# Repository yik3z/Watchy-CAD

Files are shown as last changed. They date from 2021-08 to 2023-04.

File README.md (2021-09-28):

# Watchy-CAD
Cases and hardware mods for Watchy

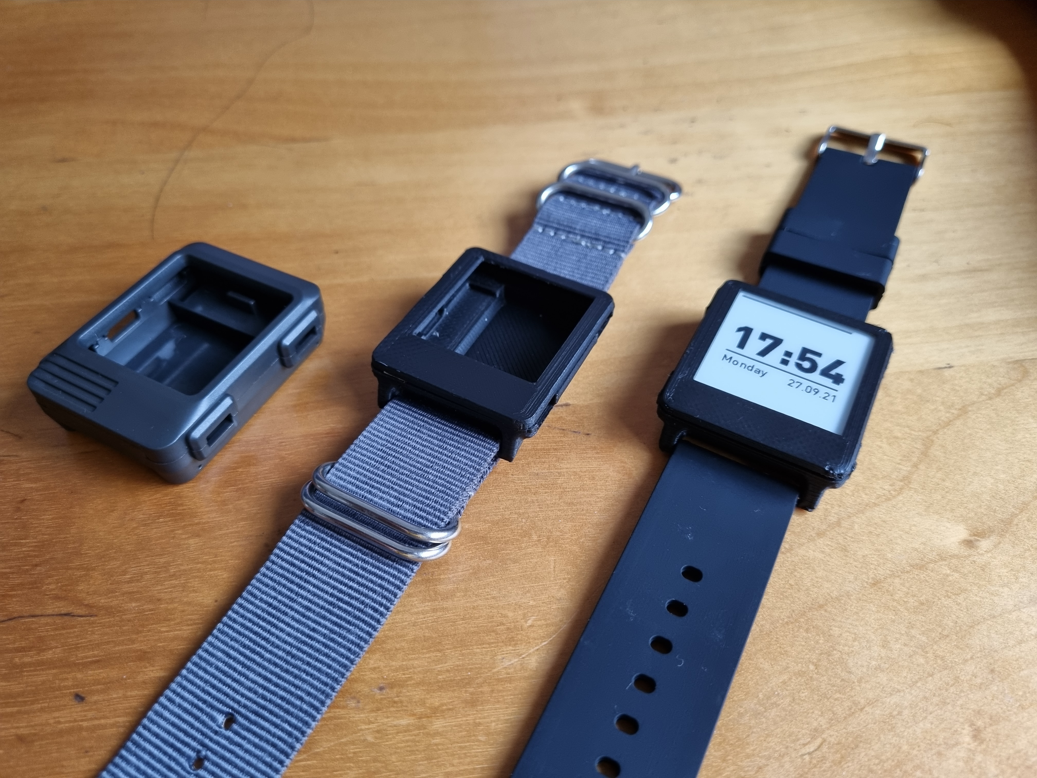
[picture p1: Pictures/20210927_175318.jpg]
Cases


# Cases
Cases are located under `CAD>Cases`. Each case design has the STLs under an `STLs` subfolder and STEP (AP214) files under the `STEP` folder.

### *Slim* cases to make Watchy less chonky

1. **Slim**: This is the original case from [SQFMI's watchy-cases](https://github.com/sqfmi/watchy-cases). Had some errors slicing the file, hence rebuilt it as Slim V2 

2. **Slim V2**: Insipred by the `Slim` case, designed for use with 24mm NATO straps.

3. **Slim V3**: **Designed for a Watchy with the watch strap loops cut off from the PCB.** Similar to Slim V2, designed for 24mm NATO straps.

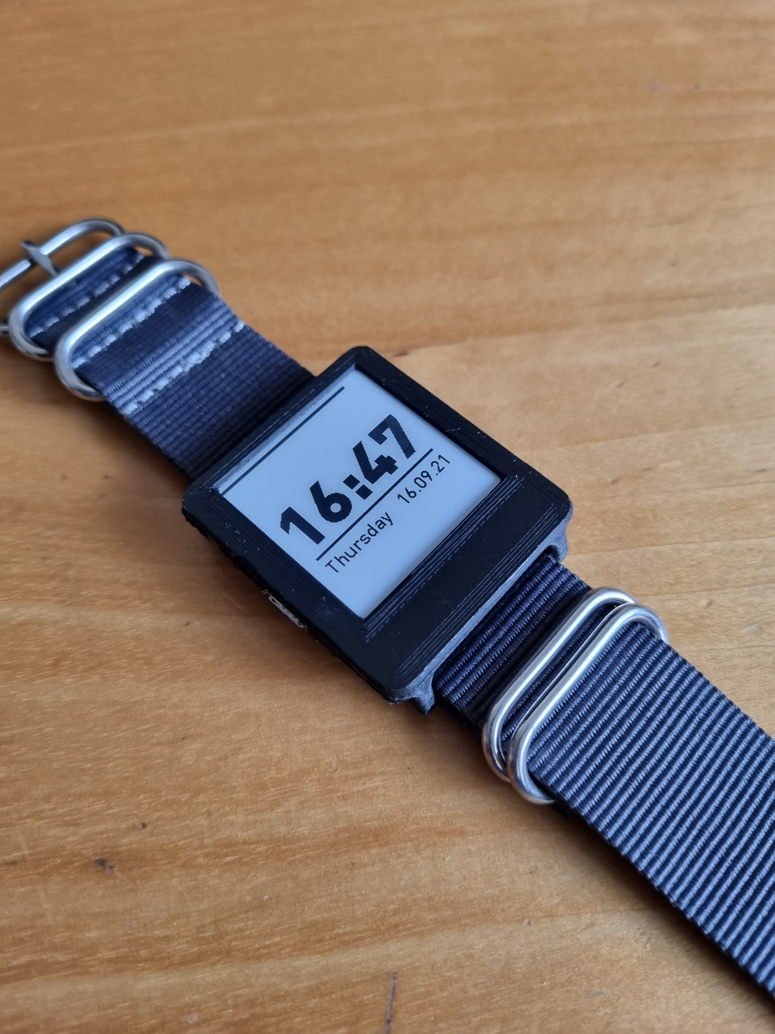
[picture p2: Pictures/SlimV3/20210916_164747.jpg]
SlimV4


I tried my hand at some discreet buttons on this, but they didn't work that well. **So, there aren't any buttons on this version.** I suggest you use the top case of `Slim V4` which has integrated buttons.

4. **Slim V4**: Similar to V3 , but tabs are changed to fit the spring pin -style straps of the Watchy starter kit (24mm). This lowers the height of Watchy significantly. 

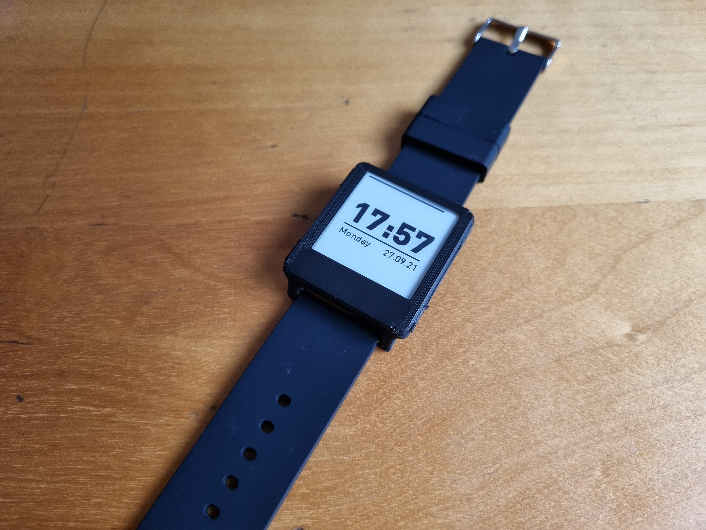
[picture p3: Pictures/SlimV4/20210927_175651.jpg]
SlimV4


In v4, I made the display window a little larger, for use with the [border colour changing 'hack' on the Watchy Discord](https://discord.com/channels/804832182006579270/808787590060048465/887013190616117288) so that the screen looks a bit bigger/bezel looks a bit smaller. If you don't want to implement the colour changing border, make the display window a little smaller (26.8mm instead of 28.4mm) otherwise there will be a white border around your display.

## Some Warnings/Notes
**Slim V3 and Slim V4 don't have any fastening mechanisms in place; they are currently held together by friction, and a bit of double-sided tape.** I find that it works well (it's pretty difficult to take the PCB out of the case, but use at your own risk). I find that the double sided tape loses it's adhesion after sticking and removing it a few times, so it's a good idea to put a fresh piece of tape every few times you take it apart.

**The Slim V3 and V4 may or may not close fully if you have the stock battery cable. I shortened mine so there is less wire taking up space in the case. [See below](##-shorten-battery-wires) for details.** It allows the case to be 1mm thinner.  If you don't want to cut the battery wires, you can just make the case 1mm deeper :P

These cases were designed on Autodesk Inventor. The raw files are included in case you'd like to modify them. 

Slim V3 and V4 parts are interchangeable (top and bottom).

Also, tolerances may vary based on 3d printer.

## Upcoming Stuff
- Clipping mechanism to make the case more secure

# Hardware Mods

## Cutting off PCB loops

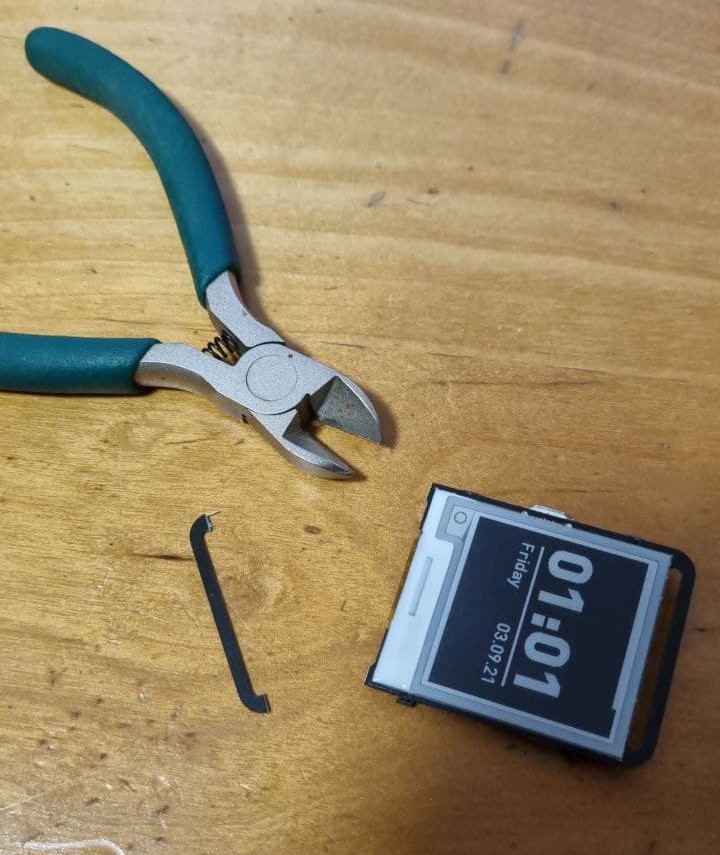
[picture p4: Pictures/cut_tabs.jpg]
cut tabs


(Guide may be coming soon)

## Shorten Battery Wires
1. Cut the wires.
2. Cut off excess.
3. Slip on some heatshrink.
4. Solder the wires back.
5. Heatshrink.

It's a good idea to do each wire separately so there's no chance that the + and - wires will ever touch.

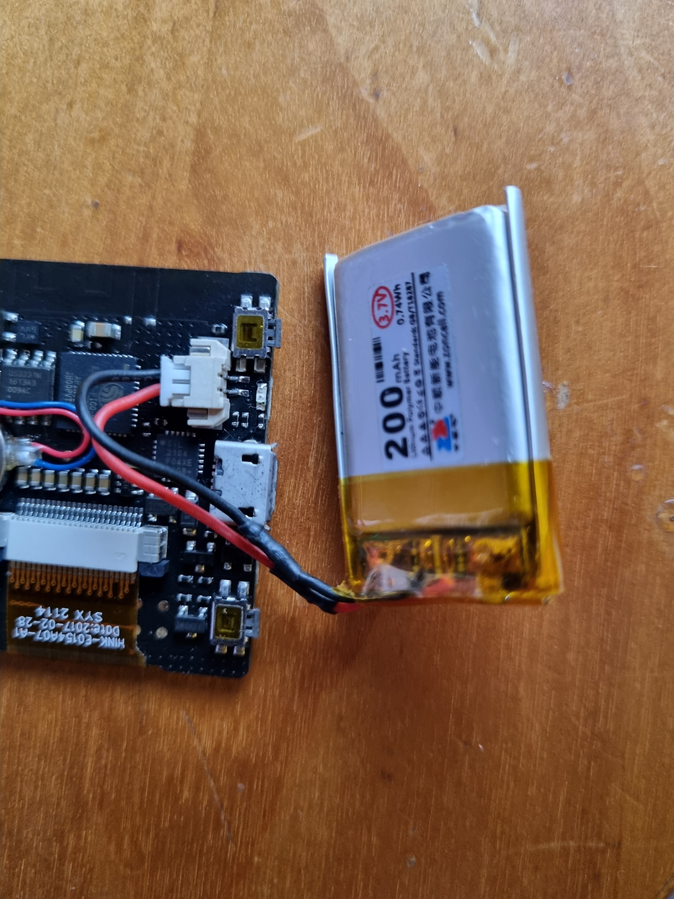
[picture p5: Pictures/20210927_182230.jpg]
shortened wire


## Touchscreen
(coming soon too hopefully hehe)
The plan: integrate [this touchscreen](https://www.good-display.com/product/258.html) with Watchy. Is currently shipping. Will update progress soon.

## Battery Charging indicator
Idea is to connect the charging controller to the ESP32's GPIO and set an interrupt so it knows when it's charging.
*Fundamentally this is problematic - Watchy may never be able to wake from sleep upon connecting a charger.*

Explanation: the charging IC pulls pin 1 low when charger is connected. ESP32 can only have one GPIO pin configured (at a time) to wake it from sleep when the pin goes low (using `ext0`). Currently that is connected to the RTC (removing that means Watchy stops being a watch). An alternative is to use an inverter, but...that's a lot of work. So this mod may not happen. At least not the wake from deep sleep part

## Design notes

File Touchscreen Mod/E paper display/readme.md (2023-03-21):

# 154M09 Display

The display might be a bit faulty because it is always very light no matter what VCOM or settings are used. (Even with Good Display's sample code).
So I have stopped development on this, and will be using the familiar 154D67 display for the touchscreen instead.

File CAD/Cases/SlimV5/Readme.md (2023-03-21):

# Version 5 of Slim Case

V5 has a bigger battery: 402535 instead of 402030
This version is for a watchy with the strap loops removed. For a smaller footprint

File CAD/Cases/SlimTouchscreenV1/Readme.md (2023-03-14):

# Version 1 of Slim Case for Touchscreen watchy

In progress

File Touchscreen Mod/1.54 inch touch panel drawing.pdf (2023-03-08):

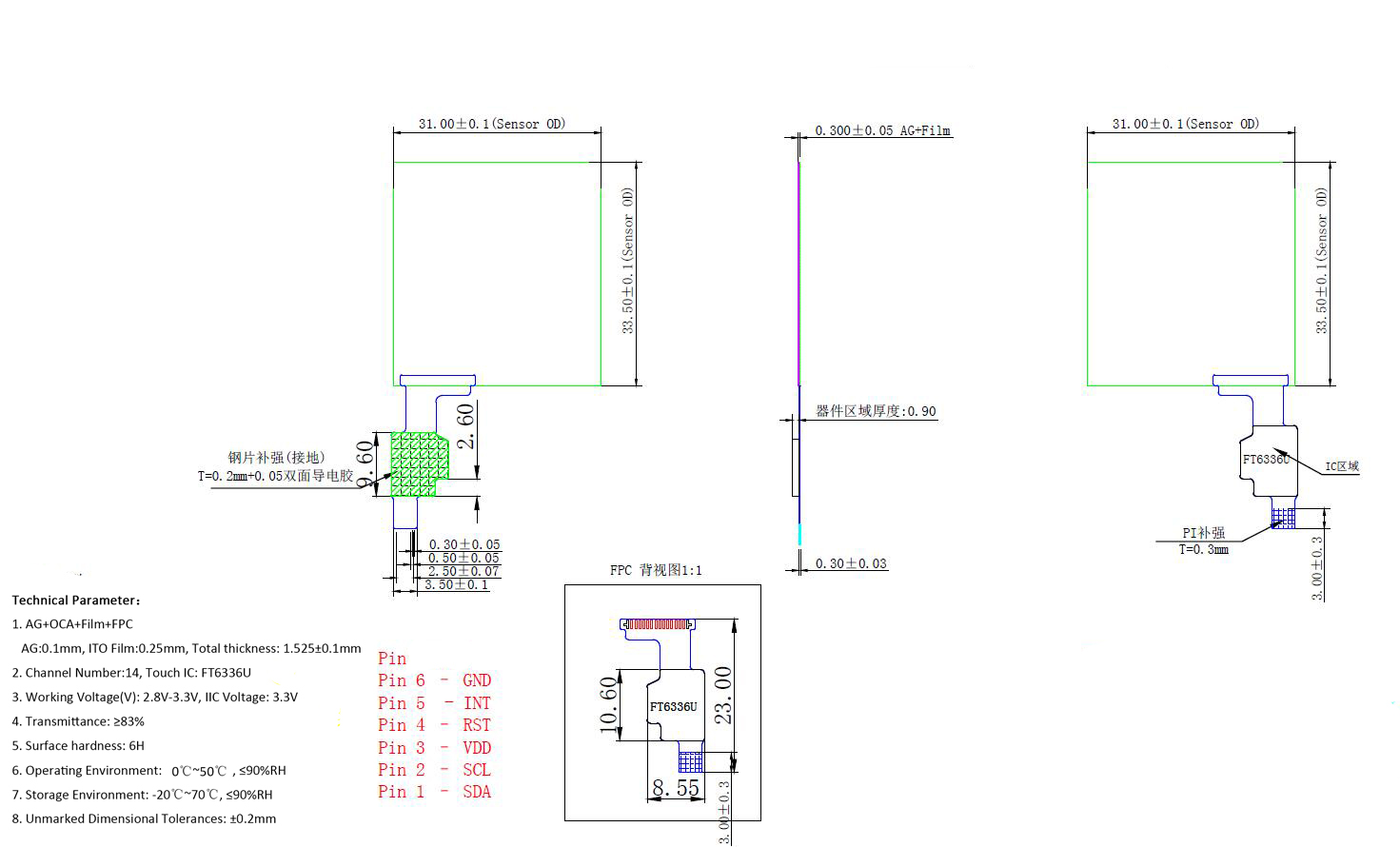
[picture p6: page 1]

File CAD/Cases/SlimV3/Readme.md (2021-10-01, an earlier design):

# Version 3 of Slim Case

This version is for a watchy with the PCB strap loops removed. For a smaller footprint

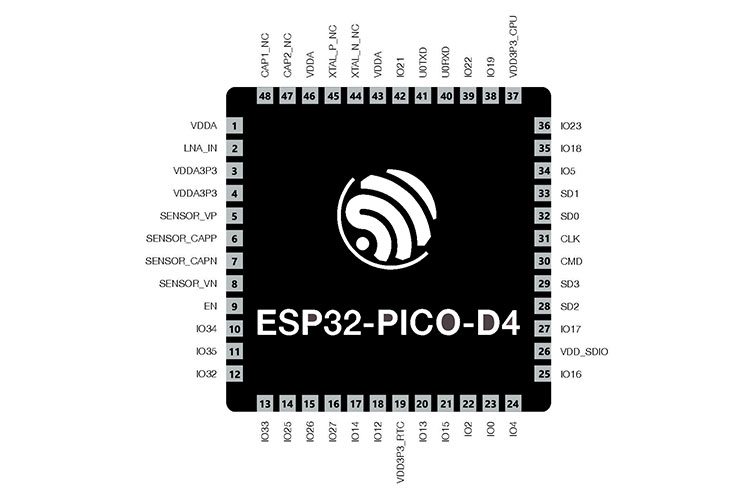
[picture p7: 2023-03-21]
Datasheets/esp32-pico-d4-pinout.jpg

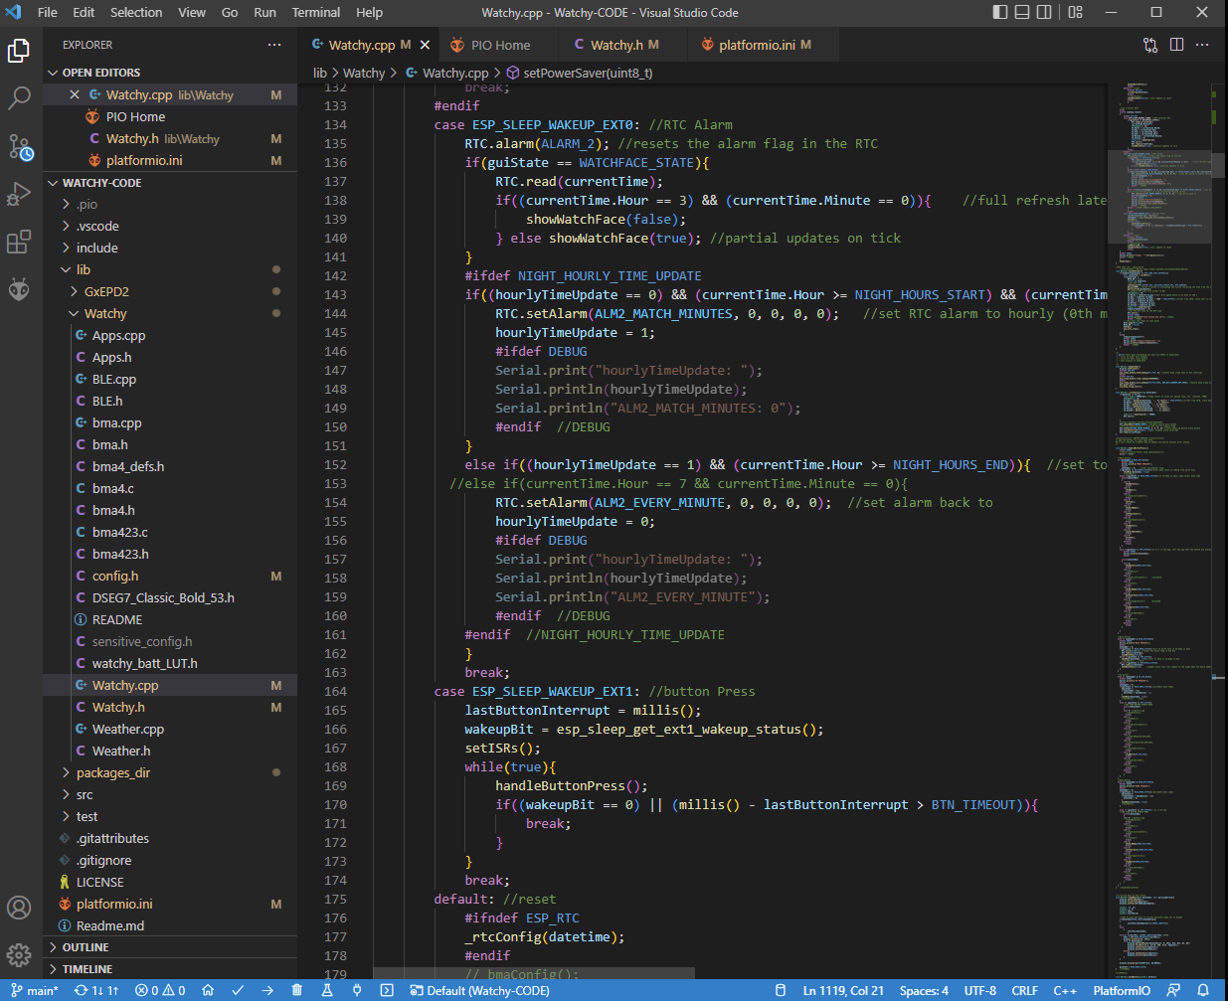
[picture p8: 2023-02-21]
Pictures/Programming.png

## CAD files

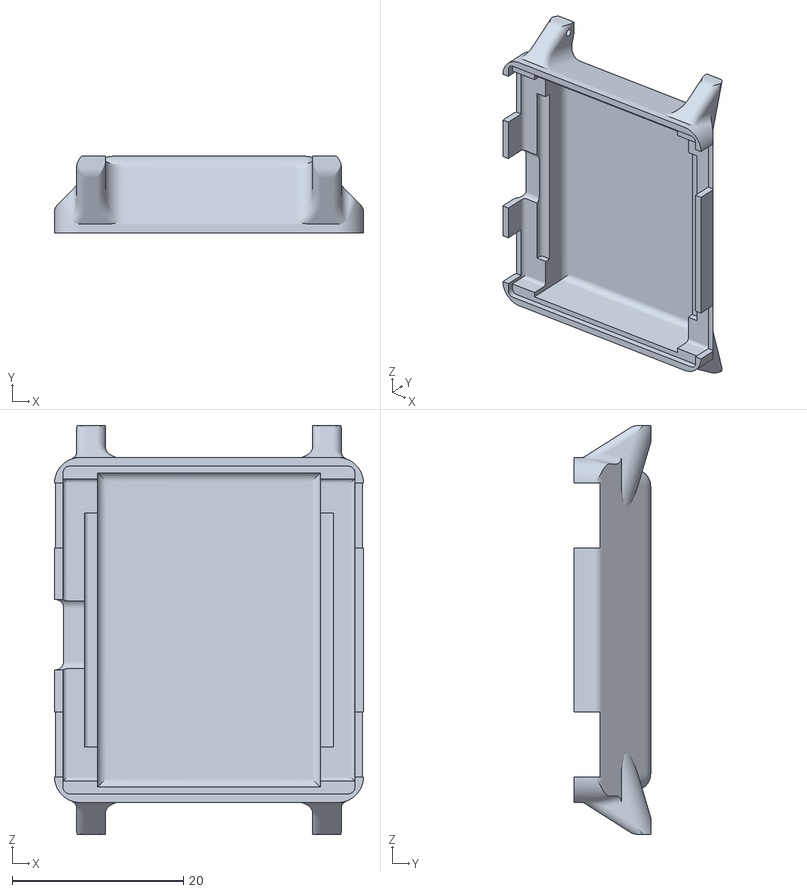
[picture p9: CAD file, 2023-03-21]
CAD/Cases/SlimV5/STLs/Bottom170323.stl
36.1 x 8.94 x 47.8

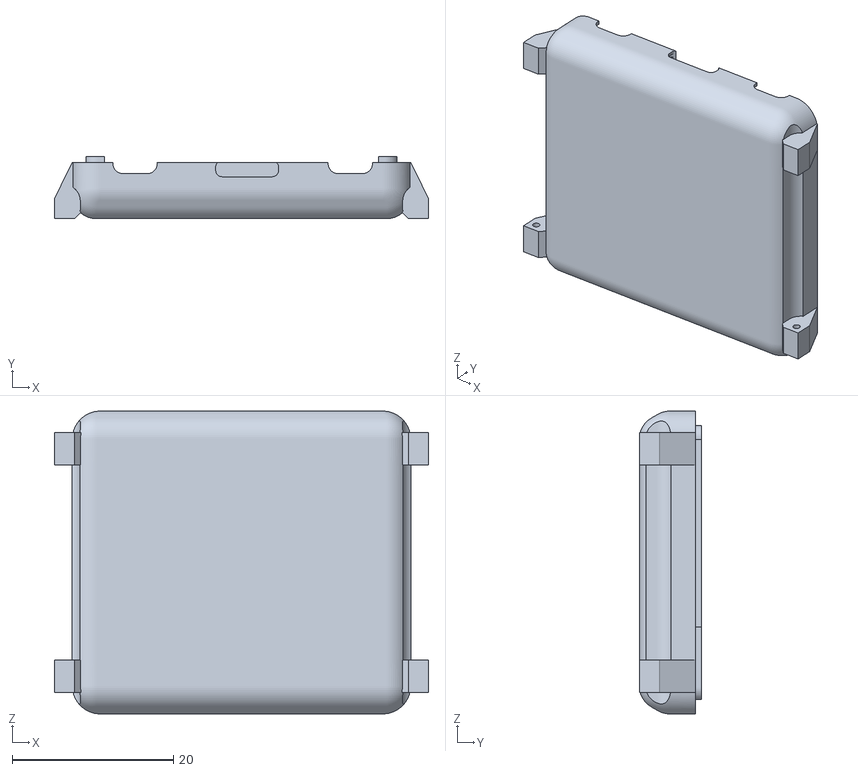
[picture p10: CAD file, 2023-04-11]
CAD/Cases/SlimTouchscreenV1/STLs/Bottom060423.stl
46.4 x 7.74 x 37.6

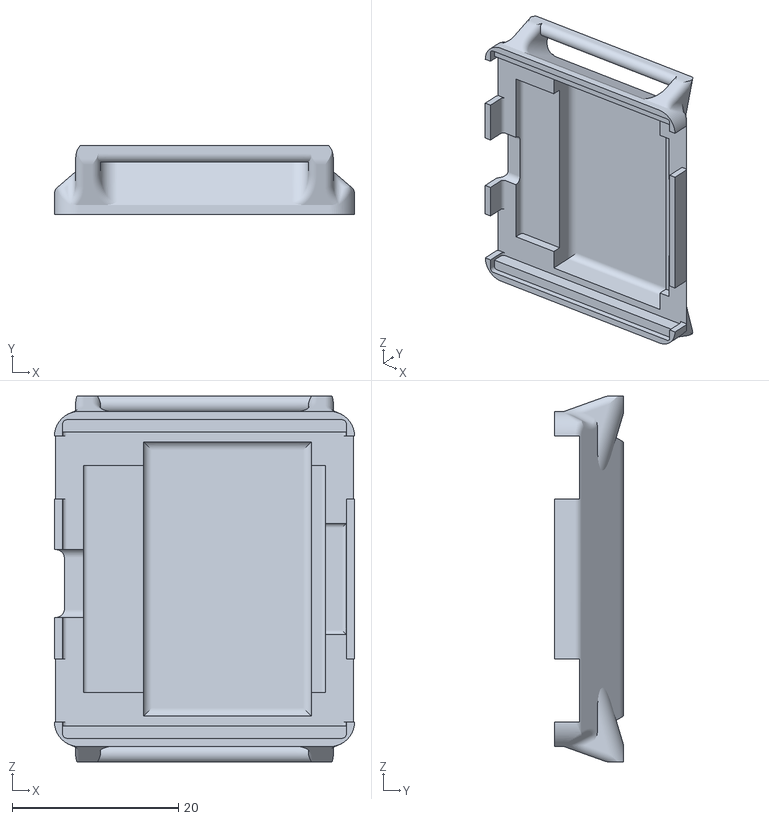
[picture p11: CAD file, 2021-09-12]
CAD/Cases/SlimV3Backup/STLs/Bottom060921.stl
36.1 x 8.34 x 44.0

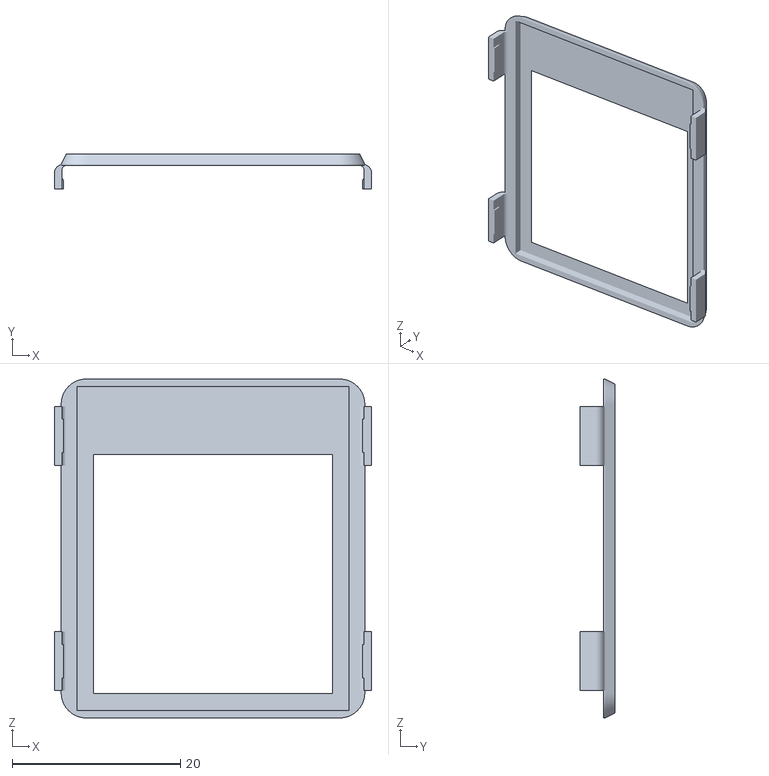
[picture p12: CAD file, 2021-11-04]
CAD/Cases/SlimV5/STLs/Top_V4 - Alt021121.stl
37.7 x 4.20 x 40.3

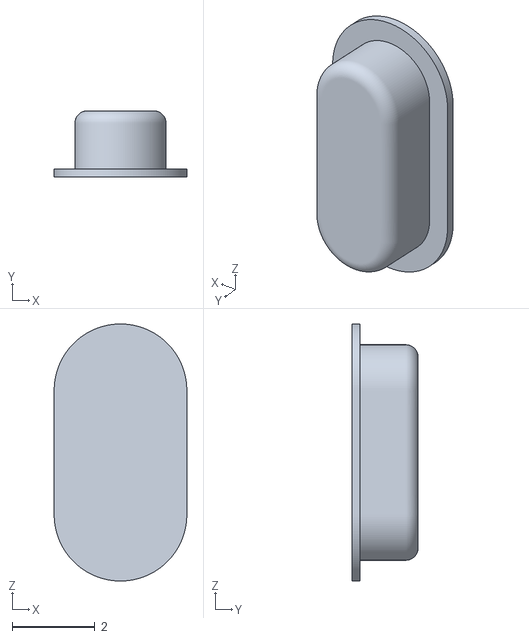
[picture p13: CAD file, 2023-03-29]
CAD/Cases/SlimTouchscreenV1/STLs/Button270323.stl
3.20 x 1.60 x 6.20

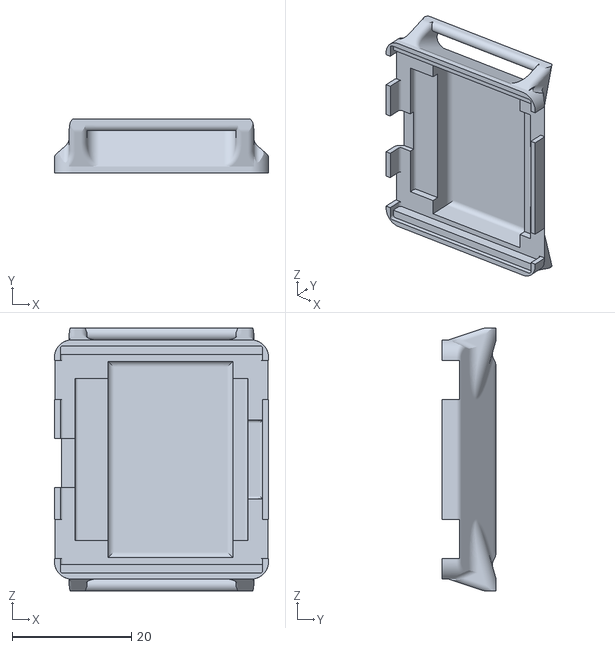
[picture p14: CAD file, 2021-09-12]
CAD/Cases/SlimV3Backup/STLs/Bottom019121.stl
36.0 x 9.14 x 44.2

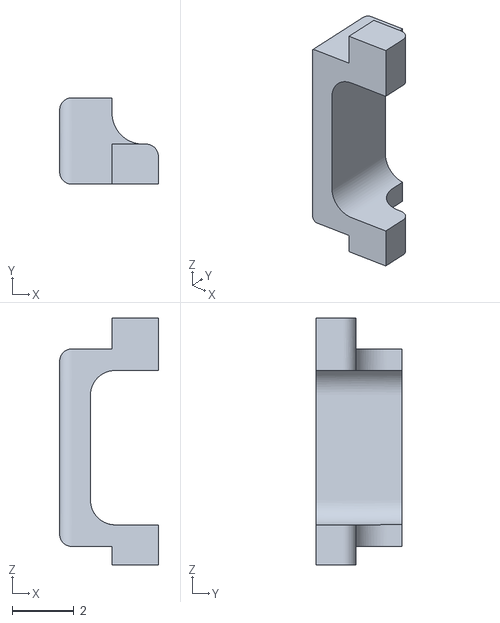
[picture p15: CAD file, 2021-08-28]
CAD/Cases/SlimV3Backup/STLs/Button1_250821.stl
3.20 x 2.80 x 8.00

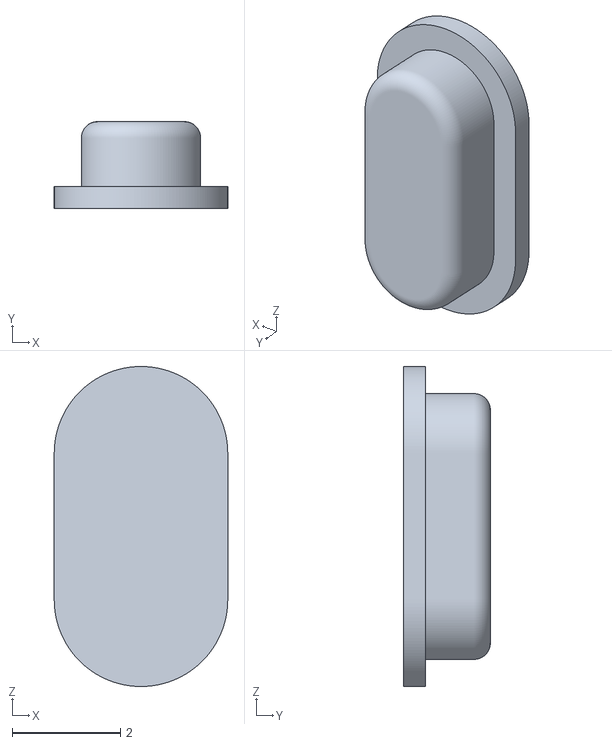
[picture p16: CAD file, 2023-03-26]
CAD/Cases/SlimTouchscreenV1/STLs/Button230323.stl
3.20 x 1.60 x 5.90

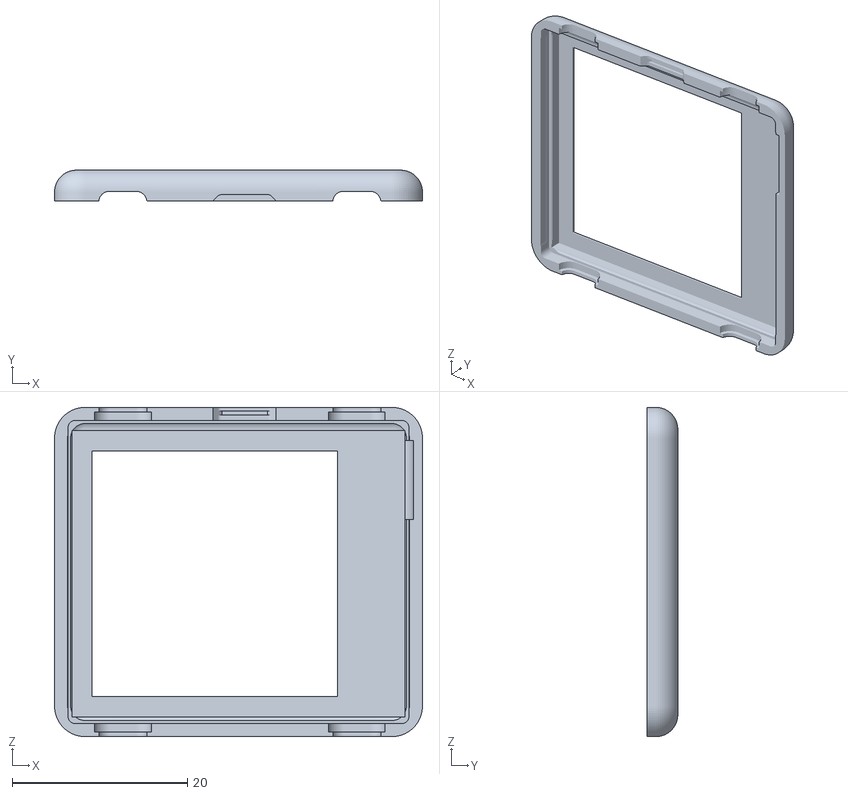
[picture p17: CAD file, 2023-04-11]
CAD/Cases/SlimTouchscreenV1/STLs/Top290323.stl
42.0 x 3.50 x 37.6

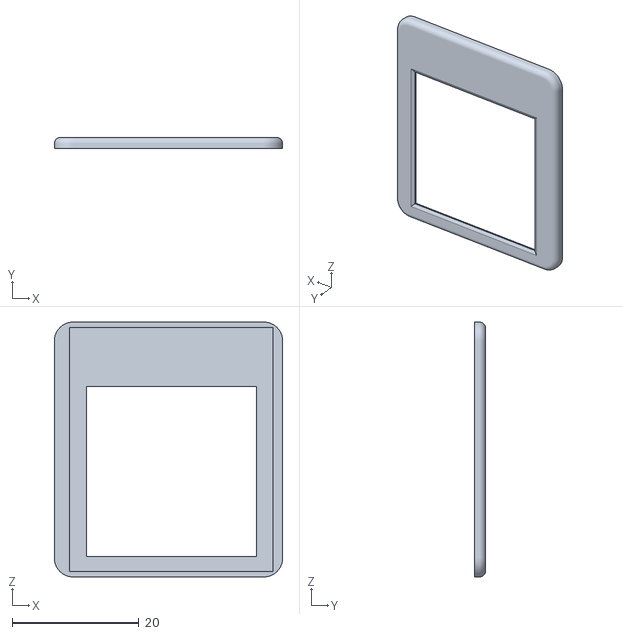
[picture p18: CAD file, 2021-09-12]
CAD/Cases/SlimV3Backup/STLs/Top010921.stl
36.0 x 1.80 x 40.2

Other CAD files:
CAD/Base Model/Battery402030.step
CAD/Base Model/Watchy_Battery.step
CAD/Cases/SlimTouchscreenV1/STLs/Bottom270323.stl
CAD/Cases/SlimTouchscreenV1/STLs/Bottom230323.stl
CAD/Cases/SlimV3Backup/STLs/Button_Mirrored1_250821.stl
CAD/Cases/SlimTouchscreenV1/STLs/Bottom170323.stl
CAD/Cases/SlimTouchscreenV1/STLs/Top310323.stl
CAD/Base Model/Battery_402030.ipt
CAD/Base Model/Battery_402535.ipt
CAD/Base Model/Button.iam
CAD/Base Model/COMPOUND (1).ipt
CAD/Base Model/COMPOUND (2).ipt
CAD/Base Model/COMPOUND (3).ipt
CAD/Base Model/COMPOUND.ipt
CAD/Base Model/COMPOUND_SMALL.ipt
CAD/Base Model/C_0603_1608Metric.iam
CAD/Base Model/C_0805_2012Metric.iam
CAD/Base Model/D_SOD-123.iam
CAD/Base Model/D_SOD-123F.iam
CAD/Base Model/Display.iam
CAD/Base Model/Display_Touchscreen.iam
CAD/Base Model/Dsiplay_Touchscreen.ipt
CAD/Base Model/FPC-24.iam
CAD/Base Model/LED_0603_1608Metric.iam
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

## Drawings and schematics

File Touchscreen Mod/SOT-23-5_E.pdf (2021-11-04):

# PACKAGE DIMENSIONS

# SOT-23-5 (MTP-5)

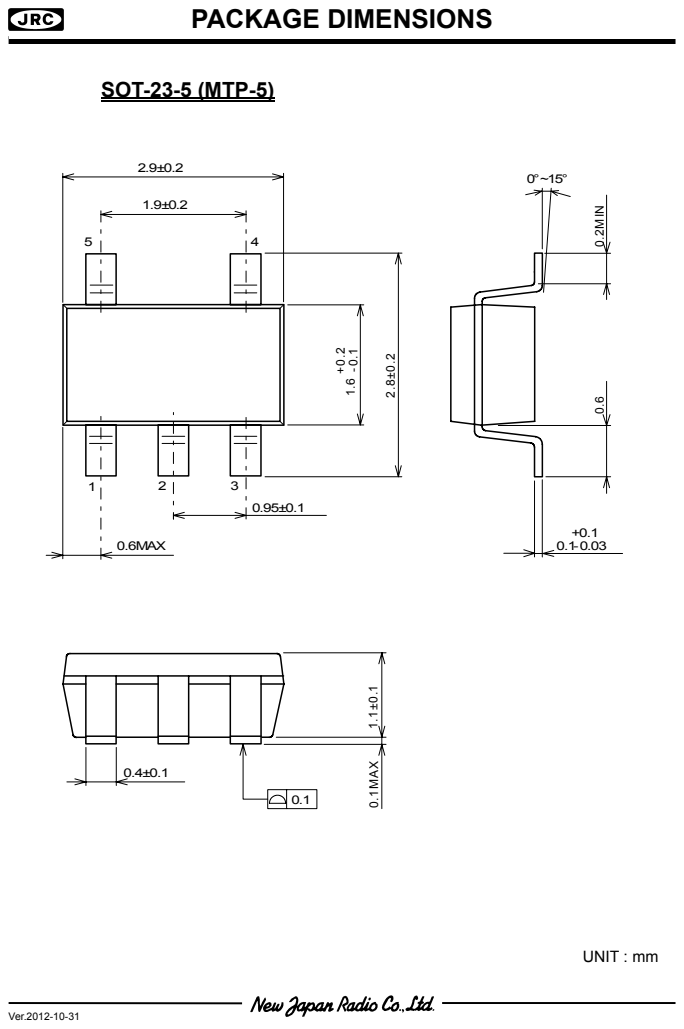
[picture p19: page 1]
UNIT : mm; Ver.2012-10-31; 0.6MAX; 0.1MAX 1.1±0.1; 0.2MIN 0.6

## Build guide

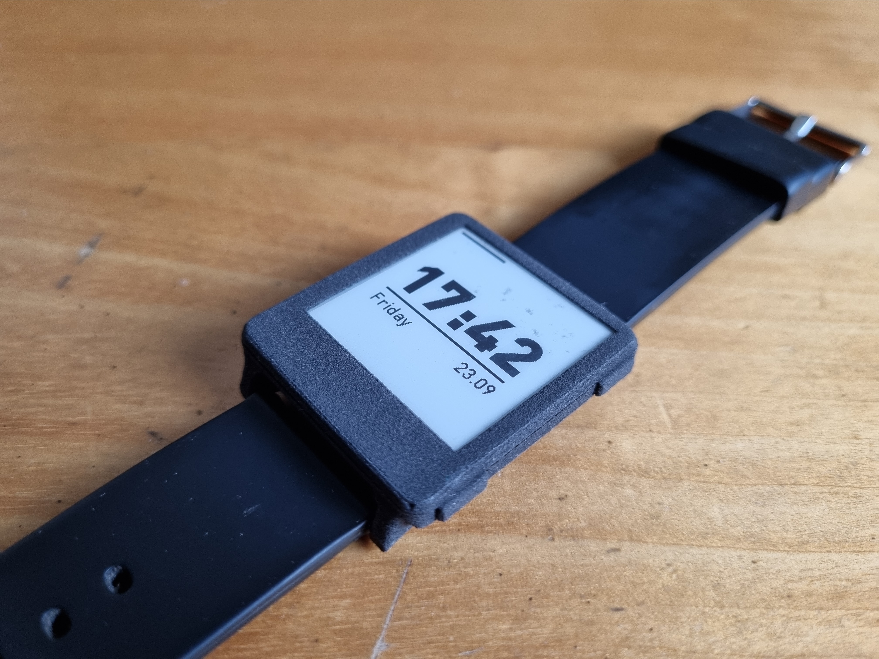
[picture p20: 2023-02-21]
Pictures/SlimV4/sls_printed.jpg

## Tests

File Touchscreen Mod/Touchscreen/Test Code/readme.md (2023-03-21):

# Touchscreen Test Code

Contains the first version of the library used to interface with the FT6336U touch IC. The library is working but will not be updated anymore (as of 21 Mar 2023).

Moving forward, developments are done in Watchy-CODE, currently under the `touchscreen_mod` branch (eventually to me merged with `main`).

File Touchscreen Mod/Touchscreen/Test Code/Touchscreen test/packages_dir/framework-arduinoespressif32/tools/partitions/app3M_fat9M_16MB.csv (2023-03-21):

# Name | Type | SubType | Offset | Size | Flags
nvs | data | nvs | 0x9000 | 0x5000
otadata | data | ota | 0xe000 | 0x2000
app0 | app | ota_0 | 0x10000 | 0x300000
app1 | app | ota_1 | 0x310000 | 0x300000
ffat | data | fat | 0x610000 | 0x9F0000
# to create/use ffat | see https://github.com/marcmerlin/esp32_fatfsimage

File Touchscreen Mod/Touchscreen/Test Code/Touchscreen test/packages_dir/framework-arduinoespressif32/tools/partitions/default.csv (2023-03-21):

# Name | Type | SubType | Offset | Size | Flags
nvs | data | nvs | 0x9000 | 0x5000
otadata | data | ota | 0xe000 | 0x2000
app0 | app | ota_0 | 0x10000 | 0x140000
app1 | app | ota_1 | 0x150000 | 0x140000
spiffs | data | spiffs | 0x290000 | 0x170000

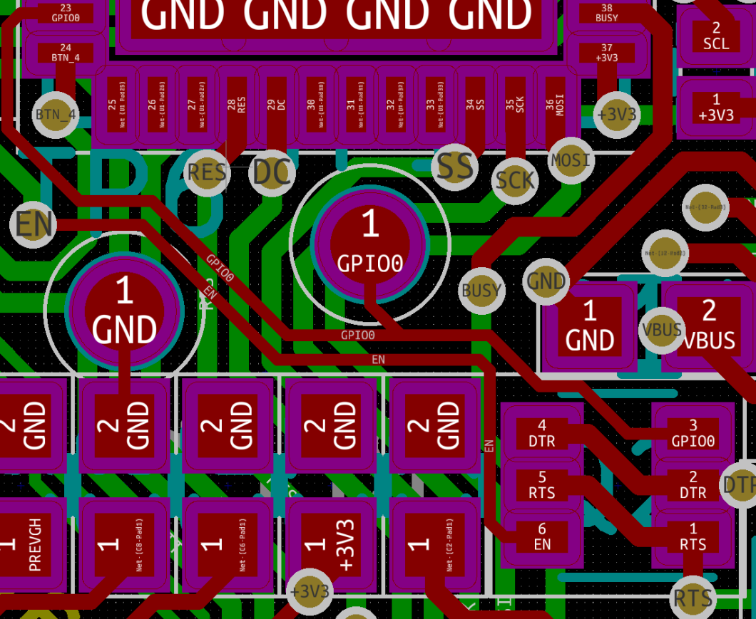
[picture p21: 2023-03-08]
Datasheets/test points 2.png

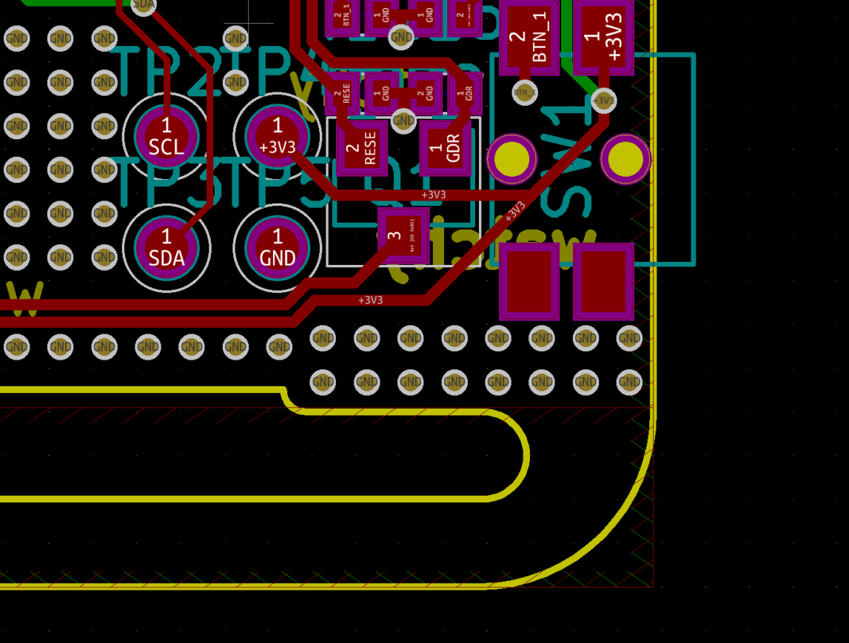
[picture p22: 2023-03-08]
Datasheets/test points.png

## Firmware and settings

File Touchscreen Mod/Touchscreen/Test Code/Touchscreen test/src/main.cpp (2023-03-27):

#include <Arduino.h>
#include <SPI.h>
#include <Wire.h>
#include "FT6336.h"

#define DEBUG_TOUCHSCREEN

#define TS_RESET_PIN     GPIO_NUM_23
#define TS_INTERRUPT_PIN GPIO_NUM_34

// The FT6336 uses hardware I2C (SCL (22)/SDA (21))
FT6336 ts = FT6336(TS_INTERRUPT_PIN, TS_RESET_PIN);
//boolean RecordOn = false;
//
//#define FRAME_X 200
//#define FRAME_Y 200
//#define FRAME_W 100
//#define FRAME_H 50

// long lastInterrupt = 0; // time when the last interrupt was fired
// long touchTimeDiff = 0; // time difference between two consecutive interrupts
// volatile bool screenTouchedFlag = 0;  // flag for interrupt
RTC_DATA_ATTR uint32_t counter = 0;

// void IRAM_ATTR touchscreenInt() {
//   screenTouchedFlag = 1;
//   touchTimeDiff = millis() - lastInterrupt;
//   lastInterrupt = millis();
//   //Serial.println("Int!");
// }

void setup(void)
{

  Wire.begin(); // GPIO 22 (SCL) and GPIO 21 (SDA)
  pinMode(TS_INTERRUPT_PIN, INPUT);
  Serial.begin(115200);
  if (esp_sleep_get_wakeup_cause() != ESP_SLEEP_WAKEUP_EXT0){ // not a touchscreen interrupt, i.e. it's the initial boot
    // digitalWrite(TS_RESET_PIN,LOW);
    // pinMode(TS_RESET_PIN, OUTPUT);
    // delay(1);
    // digitalWrite(TS_RESET_PIN,HIGH);
    // delay(300);
    if (!ts.begin(200)) { 
      Serial.println("Unable to start touchscreen.");
    } 
    else { 
      Serial.println("Touchscreen started."); 
    }
  }
  //attachInterrupt(TS_INTERRUPT_PIN, touchscreenInt, RISING);

  //esp_sleep_enable_ext0_wakeup(INTTERUPT_PIN, 0); //enable deep sleep wake on touchscreen interrupt
  //esp_deep_sleep_start();
  //if(screenTouchedFlag)
  //{   
    // Serial.print("Interrupt interval: ");
    // Serial.println(touchTimeDiff);
    // screenTouchedFlag = 0;
    // Retrieve a point  
    //delay(80); //emulate watchy powering up

    // rotate coordinate system
    // flip it around to match the screen.
    //p.x = map(p.x, 0, 240, 240, 0);
    //p.y = map(p.y, 0, 320, 320, 0);

    //screenTouchedFlag = 0;
    if(ts.touched()){    
      TS_Point p = ts.getPoint(); 
      Serial.print("Screen touched. x: ");
      Serial.print(p.x);
      Serial.print(" | y: ");
      Serial.print(p.y);
      Serial.print(" | Gesture: "); // gesture never seems to work
      Serial.print(p.gesture);
      Serial.println();
      counter++;
    // Serial.print("Pwr Mode: ");
    // Serial.print(ts.getPowerMode());
    // Serial.print(" | OpMode: "); // trying to figure out what the power modes mean
    // Serial.println(ts.getOperatingMode());
    }
    if (counter > 5){
      counter = 0;
      ts.setPowerMode(FT6336_PWR_MODE_HIBERNATE);
      Serial.print("Hibernating Display. Power Mode: ");
      Serial.println(ts.getPowerMode());    
      delay(5000);
      Serial.print("Waking Display: ");
      if(ts.wakePanel()){
        Serial.println("Wake Successful");
        ts.begin(); // init after wake from hibernate
      }else{
        Serial.println("Wake Failed");
      }
    }

    // counter++;
    // if(counter>5){  // try to hibernate the display after 5 touches
    //   counter = 0;
    //   ts.setPowerMode(FT6336_PWR_MODE_HIBERNATE);
    //   Serial.println("hibernating display");
    //   delay(200);
    //   Serial.print("Pwr Mode: ");
    //   Serial.print(ts.getPowerMode());
    //   Serial.print(" | OpMode: "); // trying to figure out what the power modes mean
    //   Serial.println(ts.getOperatingMode());
    //   ts.wakePanel();
    //   delay(100);
      
      // Serial.print("Pwr Mode: ");
    // }
  //}  
  while(digitalRead(TS_INTERRUPT_PIN)==LOW); //wait for int to clear
  //Serial.println(analogRead(TS_INTERRUPT_PIN));
  ts.setPowerMode(FT6336_PWR_MODE_MONITOR);
  esp_sleep_enable_ext0_wakeup(TS_INTERRUPT_PIN, LOW); //enable deep sleep wake on touchscreen interrupt (TODO: change to ext1)
  esp_deep_sleep_start();

}

void loop()
{
  
}

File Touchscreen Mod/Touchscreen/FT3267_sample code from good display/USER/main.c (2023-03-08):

#include "led.h"
#include "delay.h"
#include "key.h"
#include "sys.h"
#include "usart.h"
#include "exti.h"
#include "i2c.h"
#include "FT6336.h"


/************************************************
FT6336U芯片仅支持两点触控，驱动最大5寸屏。
************************************************/
    
 int main(void)
 {
	u8 i=0;		 
	delay_init();	    	 //延时函数初始化	  
	NVIC_PriorityGroupConfig(NVIC_PriorityGroup_2); //设置NVIC中断分组2:2位抢占优先级，2位响应优先级
	uart_init(115200);	 //串口初始化为115200
	LED_Init();		  		//初始化与LED连接的硬件接口 
	EXTIX_Init();
	FT6336_Init();	
	LED0=0;					//先点亮红灯 
	while(1)
	{	

				if(TPR_Structure.TouchSta &TP_COORD_UD)		//触摸有按下
		{
			TPR_Structure.TouchSta=0;	//清标记
			FT6336_Scan();					 //读取触摸坐标

			switch(touch_count)
			{
					case 1:
							if((TPR_Structure.x[0]!=0)&&(TPR_Structure.y[0]!=0)
								&&(TPR_Structure.x[0]<200)&&(TPR_Structure.y[0]<200))//软件滤掉无效操作
							{
							 printf("触摸点个数：:%d\r\n",touch_count);	//FT6336U最多支持两点触控
							 printf("x0:%d,y0:%d\r\n",TPR_Structure.x[0],TPR_Structure.y[0]);
							}
							break;
					case 2:
							if((TPR_Structure.x[0]!=0)&&(TPR_Structure.y[0]!=0)
								&&(TPR_Structure.x[1]!=0)&&(TPR_Structure.y[1]!=0)
								&&(TPR_Structure.x[0]<200)&&(TPR_Structure.y[0]<200)
								&&(TPR_Structure.x[1]<200)&&(TPR_Structure.y[1]<200))//软件滤掉无效操作
							{
							 printf("触摸点个数：:%d\r\n",touch_count);	//FT6336U最多支持两点触控
							 printf("x0:%d,y0:%d\r\n",TPR_Structure.x[0],TPR_Structure.y[0]);
							 printf("x1:%d,y1:%d\r\n",TPR_Structure.x[1],TPR_Structure.y[1]);
							}
							break;
					
					default:
						break;
						
					}
			//清空标记
				for(i=0;i<2;i++)
				{
					TPR_Structure.x[i]=0;
					TPR_Structure.y[i]=0;
				}
							
			}
	}
	 
}

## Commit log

2021-09-12 Added Slim V3
    New case (SlimV3) made to be as slim as possible
    [Bottom.0016.ipt, Bottom019121.stl, Bottom060921.stl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]
2021-09-12 Fix screen dimension
    Offset screen cutout location 0.2mm down in Top.ipt
    [Top_V3.0006.ipt, Top_V3.0007.ipt, Top_V3.ipt]
2021-09-27 Add SlimV4, Update Readme
    [Bottom.0016.ipt, Bottom019121.stl, Bottom060921.stl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]
2021-09-28 Add STEP files
    [Bottom_V4.0029.ipt, Bottom_V4.0030.ipt, Bottom_V4.ipt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]
2021-09-29 Small dimension changes to V4
    [Bottom_V4.0030.ipt, Bottom_V4.0032.ipt, Bottom_V4.ipt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]
2021-10-01 V5 first commit
    but V5 not developed yet
    [Bottom.0016.ipt, Bottom270921 1143.stl, Bottom_V3.0021.ipt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]
2021-10-05 Increase depth of case slightly
    Vibration motor was pressing on battery slightly
    [Bottom_V4.0033.ipt, Bottom_V4.0034.ipt, Bottom_V4.ipt]
2021-10-20 Thicken V4 bottom case slightly
    To accomodate for the vibration motor. Thickened by 0.4mm
    [Bottom181021.stl, Bottom_V4.0034.ipt, Bottom_V4.0035.ipt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]
2021-11-06 update v4 case top dimensions
    [Top051121.stl, Top300921.stl, Top_V4.0019.ipt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]
2021-12-25 Made top V4 - Alt but forgot what that was
    [Top_V4 - Alt.0020.ipt, Top_V4 - Alt.0021.ipt, Top_V4 - Alt.ipt]
2023-02-21 add touchscreen mod documentation
    forgot to push this months ago lol
    [Top_V4 - Alt.0020.ipt, Top_V4 - Alt.0021.ipt, Top_V4 - Alt.ipt]
2023-03-14 start on touchscreen case
    [Battery_402030.0001.ipt, Battery_402030.ipt, Battery_402535.0003.ipt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]
2023-03-21 clearance fixes for slim touchscreen v1
    [Battery_402030.0001.ipt, Battery_402030.0003.ipt, Battery_402030.ipt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]
2023-03-21 Touchscreen code working with D67 FT6336U
    - touch works with ESP sleep (latency is low enough)
    - touch points aren't missed (registers even quick touches)
    - though there is usually a phantom point with x,y = 0,0 after the main touch event
    [app3M_fat9M_16MB.csv, default.csv, default_16MB.csv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]
2023-03-21 Add readmes and ESP Pico D4 pinout
2023-03-26 hibernate and wake touchscreen works
    [Bottom230323.stl, Button230323.stl, SLIM_TC_ASSEMBLED_V1.0030.iam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]
2023-03-26 interrupt pin outputs 1.8v not 3.3v
2023-03-27 remove reset upon power on (seems it's not needed)
    [FT6336.cpp, main.cpp]
2023-03-29 increase clearance for PCB on slivtcv1 case top
    - increased the border around the pcb by 0.2mm for the top part of the case, because it seems like the PCB wouldn't fit in fully
    [Bottom270323.stl, Button.0003.ipt, Button.0004.ipt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]
2023-04-11 touchscreen case fits better
    [Bottom060423.stl, Top290323.stl, Top310323.stl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]
